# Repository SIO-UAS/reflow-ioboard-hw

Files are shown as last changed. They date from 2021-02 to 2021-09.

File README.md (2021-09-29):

# reflow-ioboard-hw
A general purpouse microcontroller board with electronics to read a pt1000 up to 300°C

# why this was designed
This board was designed to modify a genric small oven to reflow solder in it. 
The whole idea behind it was to make a very fancy reflow oven, where the UI and controlling is managed by a RPI with a touchscreen.
To Interface with a RPI there is a I2C Port on the side (the PI should also power the board via 3,3V. Yet the relays should be powerd via a 5V powersupply).
It feauters 3 screwterminals dedicated to drive relays (mosfet, no driver), 2 leds and some IO Ports.

I used a Heraeus Nexensos W-EYK 6 PT1000 aus PT1000. (Conrad Art Nr: 000172430)
Eventually you have to recalulate the resitors for the amplifier.

Yet you can use this board for many different applications.

# wireing

I hope the labeles on the board are clear enough

# software
A first version has been made. To bee seen in an other repository. 

# assembling
To assemble this board reflow soldering is adviced. (How Ironic)
I used maker paste, a stencil and a pan and some screws.

I hope this project helps you.
You are free to use it.
You are free to modify it.

Please Note: This is a project I done private, so don't expect it to be beuatiful :P

Sorry for my bad english, I'm hungry :P

If you want to support my Projects: Here is a link to Aisler where you can order the PCB (Warning: Diodes and Mosfet are not assigned):
https://aisler.net/p/IZKNMKIW

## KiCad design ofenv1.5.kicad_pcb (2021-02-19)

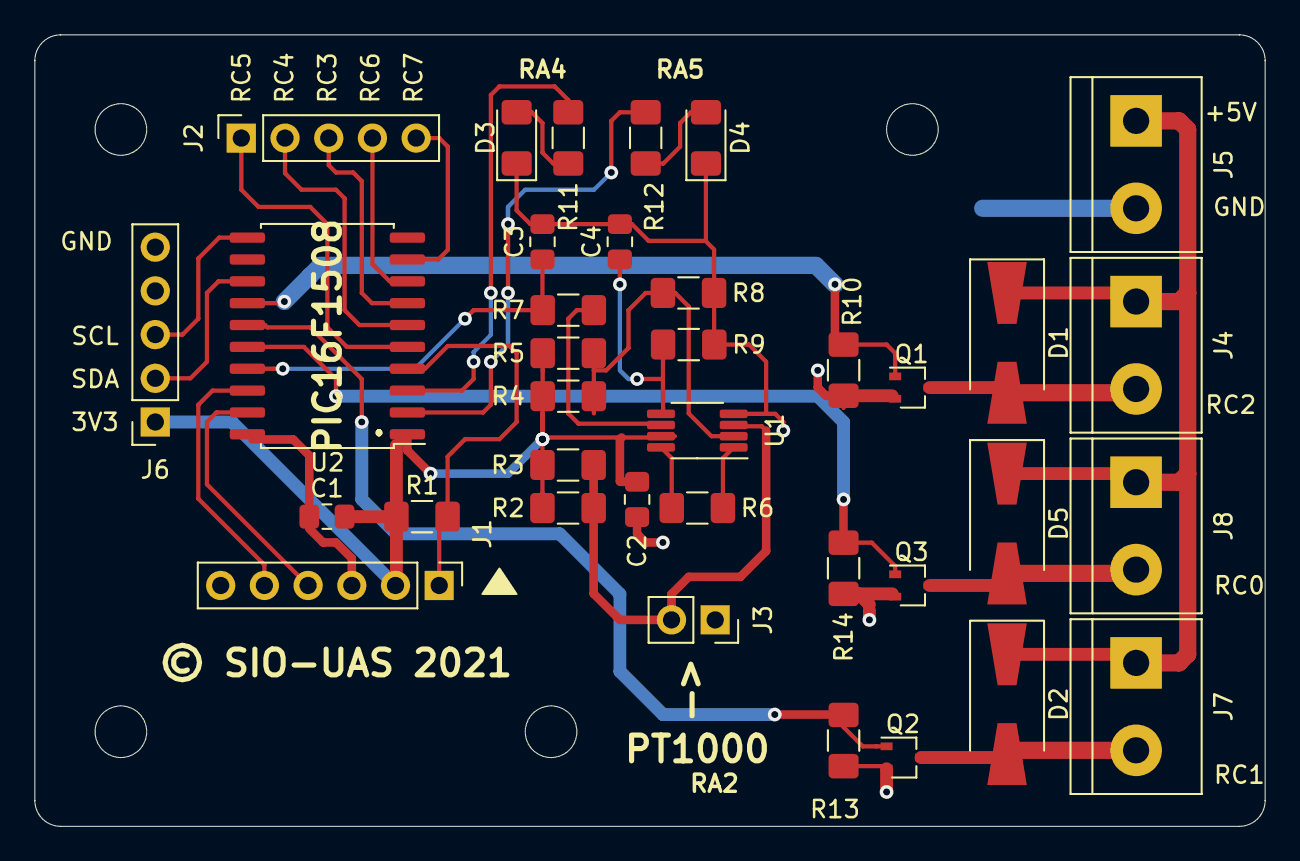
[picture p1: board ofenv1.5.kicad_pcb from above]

Board: 2 copper layers, 71.5 x 46.0 mm, 40 parts (0 on the bottom side), 30 nets.

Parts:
C1, C2: 0.1u; C_0805_2012Metric_Pad1.15x1.40mm_HandSolder
C3: 1u; C_0805_2012Metric_Pad1.15x1.40mm_HandSolder
C4: 1n; C_0805_2012Metric_Pad1.15x1.40mm_HandSolder
D1, D2, D5: D_Schottky; D_SMA-SMB_Universal_Handsoldering
D3, D4: LED; LED_1206_3216Metric_Pad1.42x1.75mm_HandSolder
H1, H2, H3, H4: MountingHole; MountingHole_3mm
J1: Conn_PIC_ICSP_ICD; PinHeader_1x06_P2.54mm_Vertical
J2, J6: Conn_01x05_Female; PinSocket_1x05_P2.54mm_Vertical
J3: Conn_01x02; PinSocket_1x02_P2.54mm_Vertical
J4, J5, J7, J8: Screw_Terminal_01x02; TerminalBlock_bornier-2_P5.08mm
Q1, Q2, Q3: BSS214NW; SOT-323_SC-70
R1, R6: 4k7; R_1206_3216Metric_Pad1.42x1.75mm_HandSolder
R2, R3, R4, R5, R9: 100k; R_1206_3216Metric_Pad1.42x1.75mm_HandSolder
R7: 100; R_1206_3216Metric_Pad1.42x1.75mm_HandSolder
R8, R10, R13, R14: 1k; R_1206_3216Metric_Pad1.42x1.75mm_HandSolder
R11, R12: 120; R_1206_3216Metric_Pad1.42x1.75mm_HandSolder
U1: INA326; MSOP-8_3x3mm_P0.65mm
U2: PIC16F1508-ISO; SOIC-20W_7.5x12.8mm_P1.27mm

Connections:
+3V3: C1.2, C2.2, J1.2, J6.1, R1.1, R2.1, R3.1, R4.1, R5.1, U1.7, U2.1
+VSW: D1.1, D2.1, D5.1, J4.1, J5.1, J7.1, J8.1
GND: C1.1, C2.1, C3.2, C4.2, D3.1, D4.1, J1.3, J3.1, J5.2, J6.5, Q1.2, Q2.2, Q3.2, R8.2, R9.2, R10.2, R13.2, R14.2, U1.4, U2.20
unnamed: C3.1, R7.1, U2.17
unnamed: C4.1, R9.1, U1.5
unnamed: D1.2, J4.2, Q1.3
unnamed: D2.2, J7.2, Q2.3
unnamed: D3.2, R11.2
unnamed: D4.2, R12.2
unnamed: D5.2, J8.2, Q3.3
unnamed: J1.1, R1.2, U2.4
unnamed: J1.4, U2.19
unnamed: J1.5, U2.18
unnamed: J2.1, U2.5
unnamed: J2.2, U2.6
unnamed: J2.3, U2.7
unnamed: J2.4, U2.8
unnamed: J2.5, U2.9
unnamed: J3.2, R2.2, R3.2, U1.3
unnamed: J6.2, U2.13
unnamed: J6.3, U2.11
unnamed: Q1.1, R10.1, U2.14
unnamed: Q2.1, R13.1, U2.15
unnamed: Q3.1, R14.1, U2.16
unnamed: R4.2, R5.2, R8.1, U1.2
unnamed: R6.1, U1.1
unnamed: R6.2, U1.8
unnamed: R7.2, U1.6
unnamed: R11.1, U2.3
unnamed: R12.1, U2.2

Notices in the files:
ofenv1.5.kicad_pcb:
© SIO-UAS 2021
